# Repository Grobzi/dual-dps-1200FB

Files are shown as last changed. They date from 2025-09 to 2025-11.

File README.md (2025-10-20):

# Dual DPS 1200FB 24V PSU

## Overview
This project demonstrates how to use two HP DPS-1200FB server PSUs in series to create a 24V power supply. An Arduino Nano R4 and a custom PCB are used to monitor and control the PSUs, with a 2.8" Arduino Shield-based touchscreen TFT for user interaction and data display.

## Features
- Monitoring of PSU parameters: current, power draw, temperature and many more.
- Touchscreen user interface (2.8" Arduino-compatible display)
- Control of 12V output in case of failure
- Basic statistics (consumed power per hour)

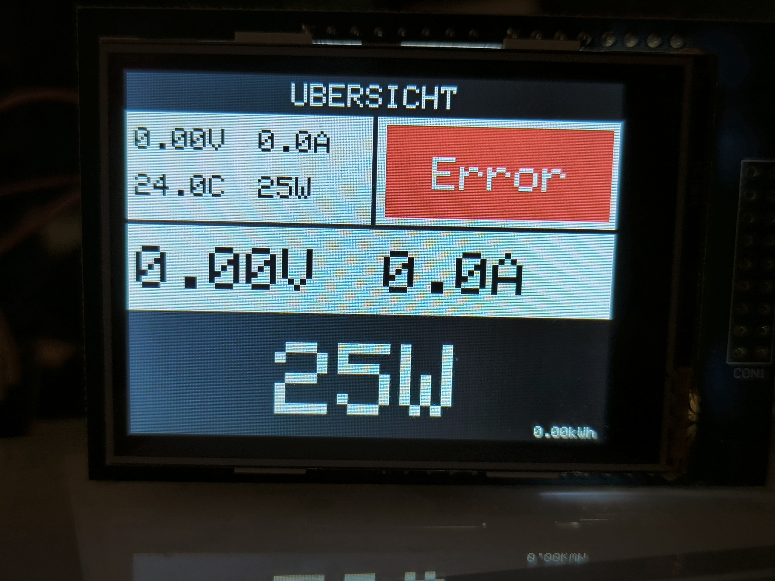
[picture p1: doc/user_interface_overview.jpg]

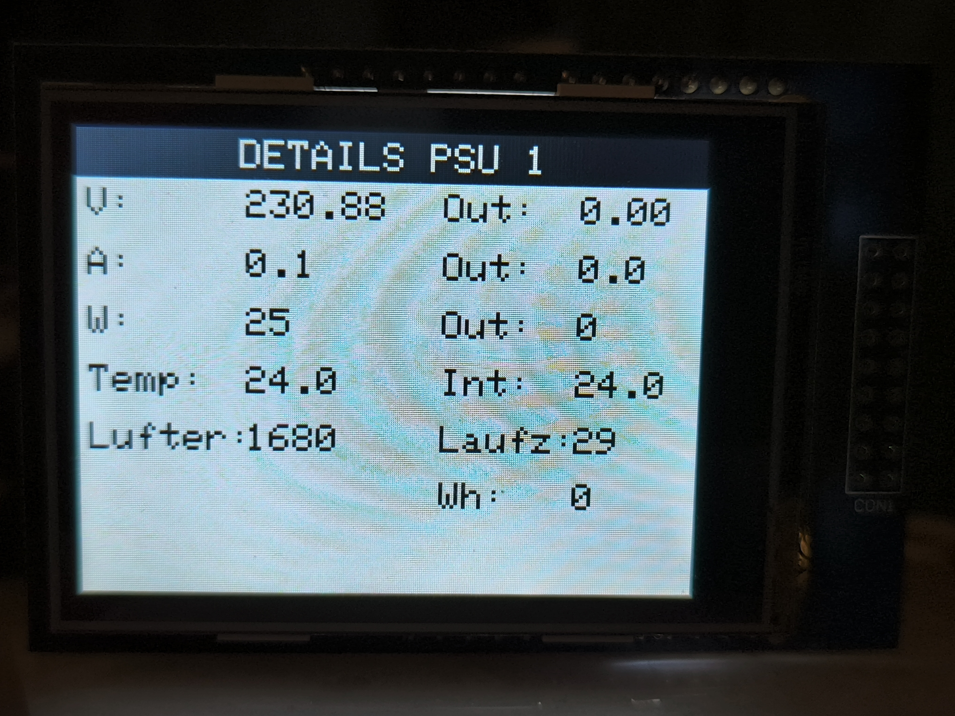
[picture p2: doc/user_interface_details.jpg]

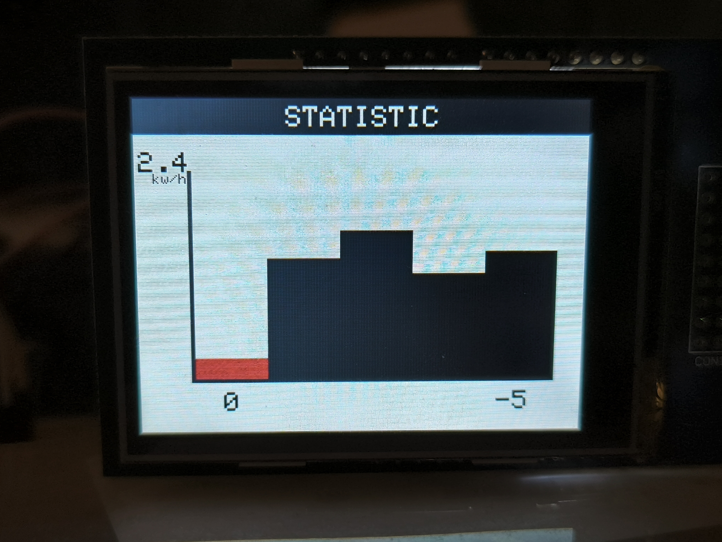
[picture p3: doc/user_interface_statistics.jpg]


## Folder Structure
- `circuit/` - KiCad project files for the custom PCB (WIP)
- `doc/` - Documentation, datasheets, and images
- `src/` - Arduino firmware source code

## Firmware
1. Open `src/PsuPowerMonitor/PsuPowerMonitor.ino` in the Arduino IDE.
2. Install required libraries
    - [MCUFRIEND_kbv](https://github.com/prenticedavid/MCUFRIEND_kbv)
    - [Adafruit GFX Library](https://github.com/adafruit/Adafruit-GFX-Library)
3. Select the correct board and port.
4. Upload the firmware to your microcontroller.

## Contributing
Contributions are welcome! Please open issues or submit pull requests for improvements, bug fixes, or new features.

# Special thanks to
- [DrTune/Raplin](https://github.com/raplin/DPS-1200FB)
- [slundell](https://github.com/slundell/dps_charger)
- [colindt](https://colintd.blogspot.com/2016/10/hacking-hp-common-slot-power-supplies.html)
- [neilp](https://www.rcgroups.com/forums/showpost.php?p=48212083&postcount=29)
- [Philipp Seidel](https://blog.seidel-philipp.de/hp-dps-1200fb-power-supply-hack-for-charging-lipos/)

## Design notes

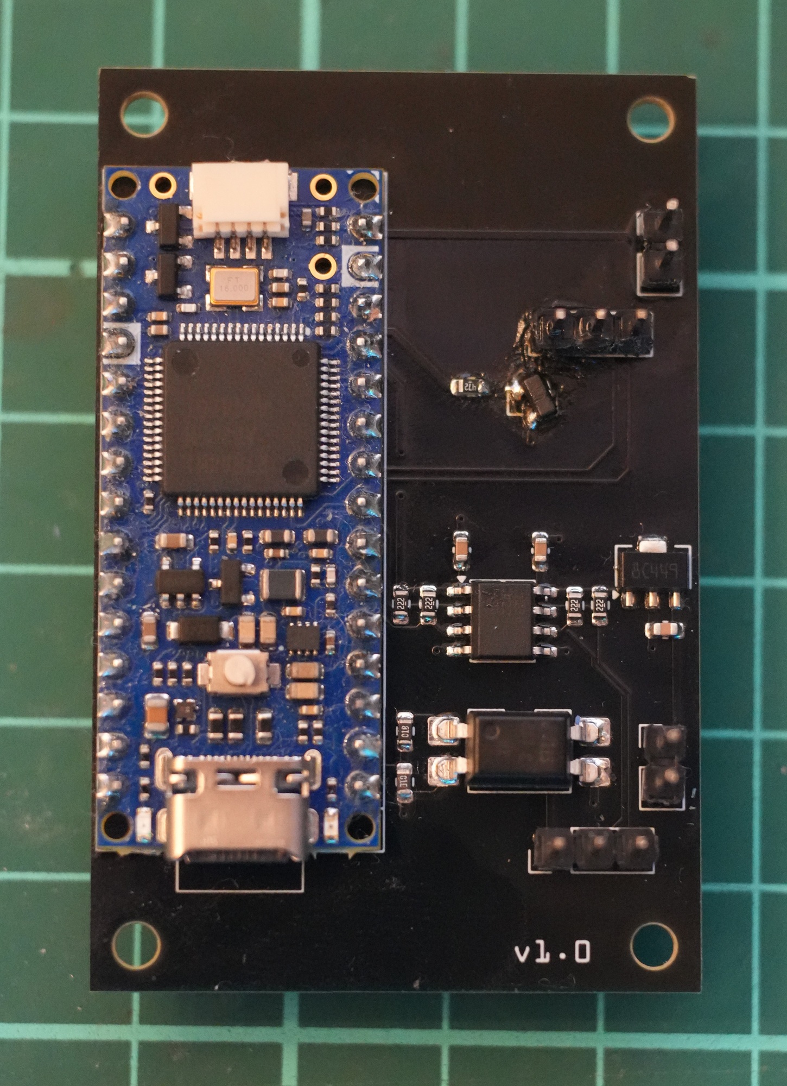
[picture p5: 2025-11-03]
circuit/PCB.JPG

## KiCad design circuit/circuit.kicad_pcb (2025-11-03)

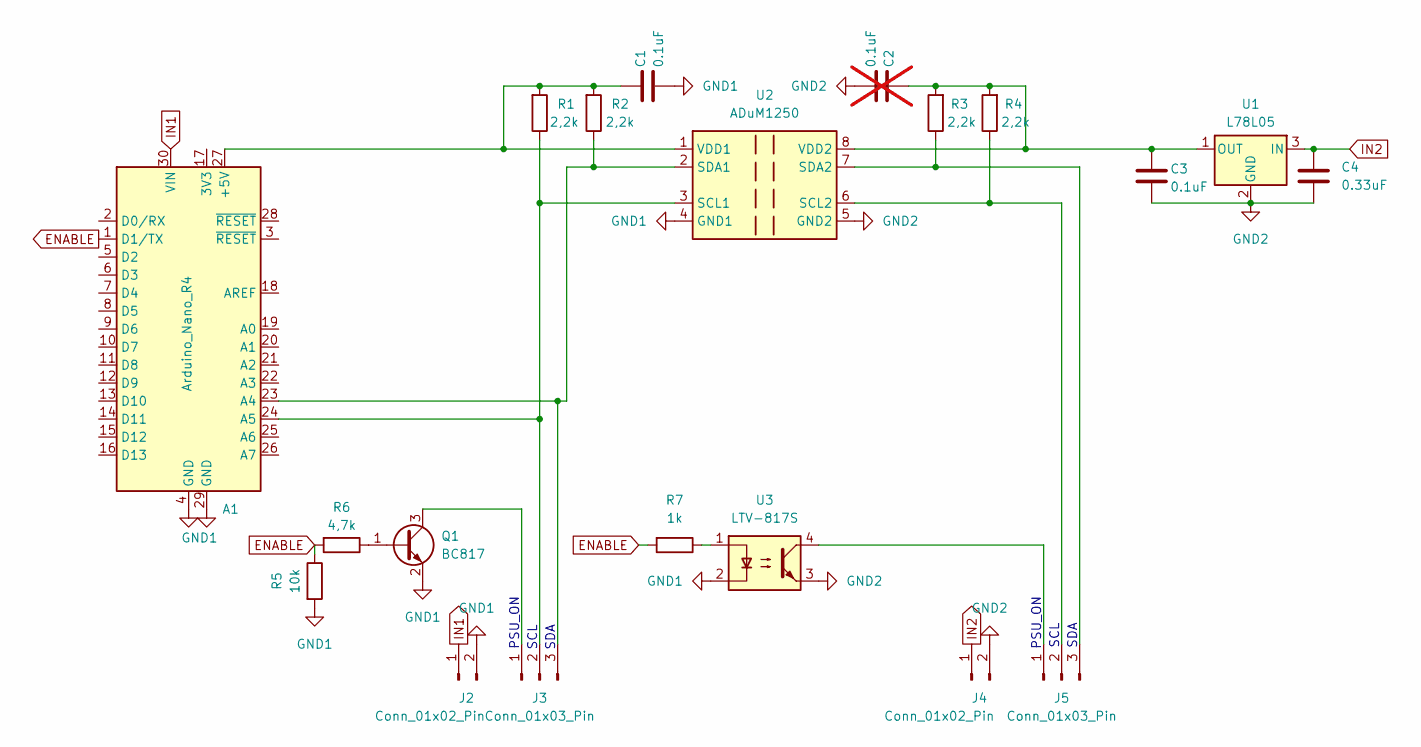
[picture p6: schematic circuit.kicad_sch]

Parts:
A1: Arduino_Nano_R4; Arduino_Nano
C1, C3: 0.1uF; C_0603_1608Metric; LCSC C125205
C2: 0.1uF; C_0603_1608Metric; not fitted
C4: 0.33uF; C_0603_1608Metric; LCSC C107070
J2, J4: Conn_01x02_Pin; PinHeader_1x02_P2.54mm_Vertical; LCSC C492401
J3, J5: Conn_01x03_Pin; PinHeader_1x03_P2.54mm_Vertical; LCSC C2937625
Q1: BC817; SOT-23
R1, R2, R3, R4: 2,2k; R_0603_1608Metric; LCSC C114662
R5: 10k; R_0603_1608Metric; LCSC C98220
R6: 4,7k; R_0603_1608Metric; LCSC C99782
R7: 1k; R_0603_1608Metric; LCSC C22548
U1: L78L05; SOT-89-3; LCSC C42738
U2: ADuM1250; SOIC-8_3.9x4.9mm_P1.27mm; LCSC C579378
U3: LTV-817S; SMDIP-4_W9.53mm; LCSC C109226

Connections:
ENABLE: A1.1 (D1/TX), R5.1, R6.2, R7.2
GND1: A1.4 (GND), A1.29 (GND), C1.2, J2.2, Q1.2 (E), R5.2, U2.4 (GND1), U3.2
GND2: C2.2, C3.2, C4.2, J4.2, U1.2 (GND), U2.5 (GND2), U3.3
IN1: A1.30 (VIN), J2.1
IN2: C4.1, J4.1, U1.3 (IN)
unnamed: A1.27 (+5V), C1.1, R1.2, R2.2, U2.1 (VDD1)
unnamed: A1.23 (A4), J3.3, R2.1, U2.2 (SDA1)
unnamed: A1.24 (A5), J3.2, R1.1, U2.3 (SCL1)
unnamed: J3.1, Q1.3 (C)
unnamed: J5.1, U3.4
unnamed: J5.2, R4.1, U2.6 (SCL2)
unnamed: J5.3, R3.1, U2.7 (SDA2)
unnamed: Q1.1 (B), R6.1
unnamed: R7.1, U3.1
unnamed: C2.1, C3.1, R3.2, R4.2, U1.1 (OUT), U2.8 (VDD2)

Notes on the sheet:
SCL
PSU_ON
SDA

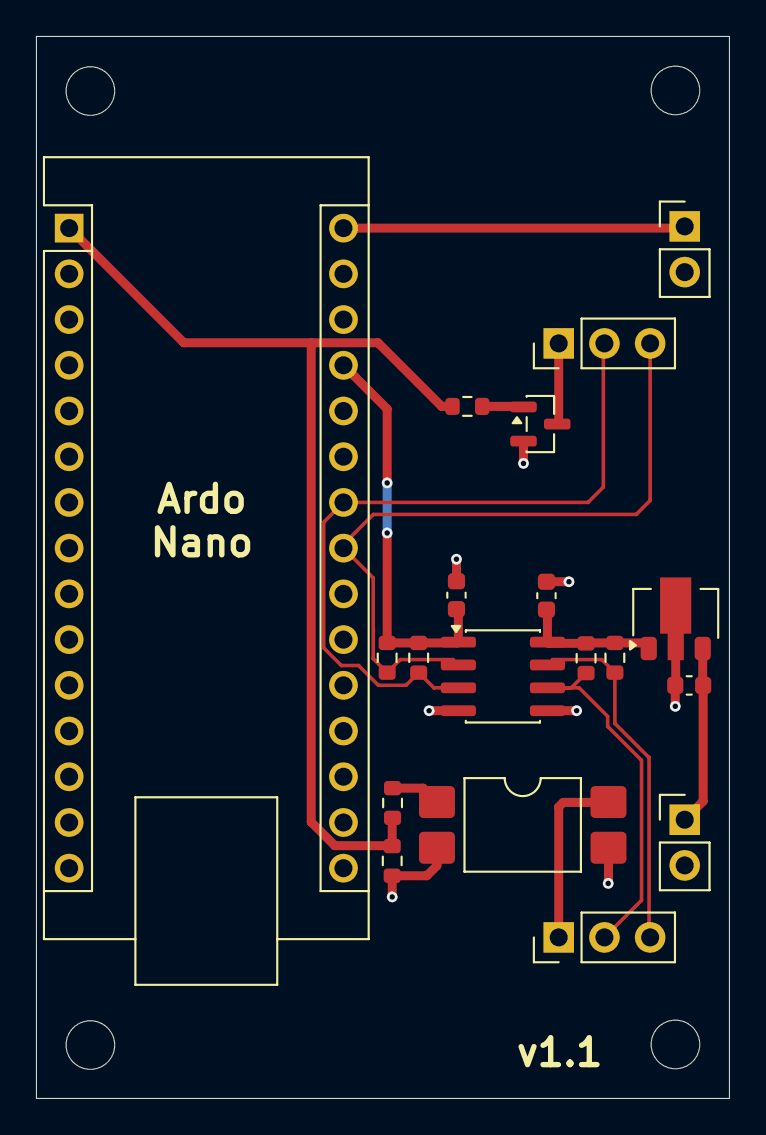
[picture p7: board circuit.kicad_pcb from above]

Board: 2 copper layers, 38.5 x 59.0 mm, 19 parts (0 on the bottom side), 15 nets.

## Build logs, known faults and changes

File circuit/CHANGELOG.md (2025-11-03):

# Changelog

## 1.1
- Use correct pinout for Q1 BC817 transitor.

## 1.0
- Inital PCB and circuit design.

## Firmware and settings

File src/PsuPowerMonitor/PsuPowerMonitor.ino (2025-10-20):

#include "Psu.hpp"
#include "TouchScreen_kbv.h"
#include "Views.hpp"

#include <MCUFRIEND_kbv.h>
#include <Wire.h>
#include <vector>

#define TouchScreen TouchScreen_kbv
#define TSPoint TSPoint_kbv
#define XP 8
#define YP A3
#define XM A2
#define YM 9
#define ENABLE_PIN D1

Psu psu_0 = Psu(0x5F);
Psu psu_1 = Psu(0x5C);
MCUFRIEND_kbv tft;
TouchScreen ts(8, YP, XM, YM, 300);
TSPoint tp;
PsuView view_0 = PsuView(tft, 5, 30);
PsuView view_1 = PsuView(tft, 168, 30);
PsuDetailView detail_view = PsuDetailView(tft, 0, 25);
ChangeableText voltage_text = ChangeableText(tft, 5, 112, 4, BLACK, WHITE);
ChangeableText current_text = ChangeableText(tft, 168, 112, 4, BLACK, WHITE);
ChangeableText power_text = ChangeableText(tft, 180, 175, 7, WHITE, GRAY);
ChangeableText power_combined_text = ChangeableText(tft, 180, 175, 1, WHITE, GRAY);
std::vector<uint32_t> consumption_per_hour = {0};

void setup()
{
    Wire.setTimeout(10);
    Wire.begin();
    Serial.begin(9600);
    pinMode(ENABLE_PIN, PinMode::OUTPUT);
    // while (!Serial);
    tft.begin();
    tft.setRotation(1);
    tft.cp437(true);
}

// State machine variables
enum State
{
    Init,
    Overview,
    Detail,
    Statistics,
    Settings
};
State state = State::Init;
State last_state = State::Init;
int8_t selected_psu;

void display_loop()
{
    static uint32_t last_draw_time = 0;
    uint32_t time = millis();
    if (last_state == state)
    {
        if (time < last_draw_time)
            last_draw_time = 0;
        if (time - last_draw_time < 500)
            return;
    }
    last_draw_time = time;

    if (state == State::Init)
    {
        last_state = state;
        tft.fillScreen(RED);
        tft.setCursor(10, 10);
        tft.setTextColor(WHITE);
        tft.setTextSize(1);
        tft.print("Connect to PSU 1... ");
        delay(100);
        psu_0.connect();
        tft.print(psu_0.connected() ? psu_0.spn.c_str() : "FAILED");
        tft.setCursor(10, 20);
        tft.print("Connect to PSU 2... ");
        delay(100);
        psu_1.connect();
        tft.print(psu_1.connected() ? psu_1.spn.c_str() : "FAILED");
        delay(100);
        if (!psu_0.connected() || !psu_1.connected())
        {
            delay(500);
        }

        state = State::Overview;
    }

    if (state == State::Overview)
    {
        if (last_state != state)
        {
            last_state = state;
            draw_banner(tft, "UBERSICHT");
            tft.fillRect(0, 25, tft.width(), tft.height(), WHITE);
            tft.fillRect(tft.width() / 2 - 1, 25, 3, 70, GRAY);
            tft.fillRect(0, 95, tft.width(), 3, GRAY);
            tft.fillRect(0, 155, tft.width(), 100, GRAY);
            Serial.println("Main layout drawn");
            current_text.set_text("");
            voltage_text.set_text("");
            power_text.set_text("");
            power_combined_text.set_text("");
            view_0.invalidate();
            view_1.invalidate();
        }

        float combined_voltage = 0;
        float combined_current = 0;
        float combined_power = 0;
        float combined_power_used = 0;
        for (int i = 0; i <= 1; i++)
        {
            PsuView *view = &view_0;
            Psu *psu = &psu_0;
            if (i == 1)
            {
                view = &view_1;
                psu = &psu_1;
            }
            if (psu->connected())
            {
                combined_voltage += psu->voltage_out();
                combined_current += psu->current_out();
                combined_power += psu->power_in();
                combined_power_used += psu->power_consumed();
                view->set_state(PsuState::normal);
                view->initial_draw();
                view->update_draw(format_precision(psu->voltage_out(), 2), format_precision(psu->current_out(), 1),
                                  format_precision(psu->temperature_internal(), 1),
                                  format_precision(psu->power_in(), 0));
            }
            else
            {
                view->set_state(PsuState::error);
                view->initial_draw();
            }
        }

        voltage_text.set_text(format_precision(combined_voltage, 2) + "V");
        current_text.set_text(format_precision(combined_current / 2, 1) + "A");
        int16_t x1, y1;
        uint16_t w, h;
        std::string text = format_precision(combined_power, 0) + "W";
        tft.setTextSize(7);
        tft.getTextBounds(text.c_str(), 0, 0, &x1, &y1, &w, &h);
        power_text.set_text(text, (tft.width() - w) / 2, 175);

        text = format_precision(combined_power_used / 1000, 2) + "kWh";
        tft.setTextSize(1);
        tft.getTextBounds(text.c_str(), 0, 0, &x1, &y1, &w, &h);
        power_combined_text.set_text(text, (tft.width() - w - 5), 230);
    }

    if (state == State::Detail)
    {
        if (last_state != state)
        {
            last_state = state;
            detail_view.invalidate();
            if (selected_psu == 0)
                draw_banner(tft, "DETAILS PSU 1");
            if (selected_psu == 1)
                draw_banner(tft, "DETAILS PSU 2");
            detail_view.initial_draw();
        }
        Psu *psu = &psu_0;
        if (selected_psu == 1)
            psu = &psu_1;
        if (psu->connected())
            detail_view.update_draw(
                format_precision(psu->voltage_in(), 2), format_precision(psu->voltage_out(), 2),
                format_precision(psu->current_in(), 1), format_precision(psu->current_out(), 1),
                format_precision(psu->power_in(), 0), format_precision(psu->power_out(), 0),
                format_precision(psu->temperature_intake(), 1), format_precision(psu->temperature_internal(), 1),
                format_precision(psu->fan_speed(), 0), format_precision(psu->seconds_since_startup(), 0),
                format_precision(psu->power_consumed(), 0));
    }

    if (state == State::Statistics)
    {
        constexpr int graph_width = 260;
        constexpr int graph_height = 150;
        constexpr int bars_count = 5;
        constexpr int bars_width = graph_width / bars_count;
        constexpr int x_pos = 40;

        static auto last_hour = 0;
        if (last_state != state || last_hour != consumption_per_hour.size())
        {
            last_hour = consumption_per_hour.size();
            last_state = state;
            draw_banner(tft, "STATISTIC");
            tft.fillRect(0, 25, tft.width(), tft.height(), WHITE);
            tft.fillRect(x_pos - 3, 200, graph_width + 3, 3, GRAY);
            tft.fillRect(x_pos - 3, 200, 3, -graph_height, GRAY);
            tft.setTextColor(BLACK);
            tft.setCursor(x_pos + 20, 210);
            tft.print("0");
            tft.setCursor(258, 210);
            tft.print("-5");
            tft.setCursor(3, 37);
            tft.print("2.4");
            tft.setTextSize(1);
            tft.setCursor(13, 52);
            tft.print("kw/h");
            for (int i = 0; i < bars_count; i++)
            {
                if (i >= consumption_per_hour.size())
                    break;
                // Maximum should be 2400Wh
                auto consumption = consumption_per_hour[consumption_per_hour.size() - i - 1];
                auto bar_height = (consumption / 2400.f) * graph_height;
                tft.fillRect(x_pos + bars_width * i, 200, bars_width, -bar_height, GRAY);
            }
        }

        static uint32_t flicker = 0;
        flicker++;
        auto consumption = consumption_per_hour.back();
        auto bar_height = (consumption / 2400.f) * graph_height;
        bar_height = std::max(1.f, bar_height);
        if (flicker % 2)
            tft.fillRect(x_pos, 200, bars_width, -bar_height, GRAY);
        else
            tft.fillRect(x_pos, 200, bars_width, -bar_height, RED);
    }
}

void collect_statistics_loop()
{
    static uint32_t last_time = 0;
    uint32_t time = millis();
    if (time < last_time)
        last_time = 0;
    if (time - last_time < 1000 * 30)
        return;
    last_time = time;

    auto hour = millis() / 1000 / 60 / 60;
    if (hour >= consumption_per_hour.size())
        consumption_per_hour.push_back(0);
    auto consumed = psu_0.power_consumed() + psu_1.power_consumed();
    for (int i = 0; i < hour; i++)
        consumed -= consumption_per_hour[i];
    Serial.print("Refresh statistics for hour ");
    Serial.println(hour);
    consumption_per_hour[hour] = consumed;
}

void touch_loop()
{
    auto p = ts.getPoint();
    // restore shared pins
    pinMode(YP, OUTPUT);
    pinMode(XM, OUTPUT);
    digitalWrite(YP, HIGH);
    digitalWrite(XM, HIGH);
    if (p.z < 100)
        return;
    auto x = map(p.y, 913, 165, 0, tft.width());
    auto y = map(p.x, 172, 846, 0, tft.height());
    Serial.print("Touch on: ");
    Serial.print(x);
    Serial.print("x");
    Serial.print(y);
    Serial.print("|");
    Serial.println(p.z);
    if (state == State::Init)
    {
        // No touch operation
    }

    if (state == State::Overview)
    {
        if (x > 0 && x < 150 && y > 30 && y < 80)
        {
            selected_psu = 0;
            state = State::Detail;
            display_loop();
        }
        else if (x > 210 && x < 300 && y > 30 && y < 80)
        {
            selected_psu = 1;
            state = State::Detail;
            display_loop();
        }
        else if (y > 180)
        {
            state = State::Statistics;
            display_loop();
        }
    }

    if (state == State::Detail)
    {
        if (y > 0 && y < 40)
        {
            selected_psu = -1;
            state = State::Overview;
            display_loop();
        }
    }
    if (state == State::Statistics)
    {
        if (y > 0 && y < 40)
        {
            state = State::Overview;
            display_loop();
        }
    }
}

uint32_t output_error_time = 0;
bool output_error = false;

void enable_signal_loop()
{
    if (psu_0.connected() && psu_0.voltage_in() > 0 && psu_1.connected() && psu_1.voltage_in() > 0)
    {
        if (!output_error)
            digitalWrite(ENABLE_PIN, PinStatus::HIGH);

        // Make sure that  300ms after the outputs are enabled the PSUs outputs are active
        // If not switch the outputs off again.
        if (psu_0.voltage_out() <= 0 || psu_1.voltage_out() <= 0)
        {
            if (output_error_time == 0)
            {
                output_error_time = millis();
            }
            if (millis() - output_error_time > 300)
            {
                digitalWrite(ENABLE_PIN, PinStatus::LOW);
                output_error = true;
            }
        }
        else
        {
            output_error_time = 0;
        }
    }
    else
    {
        digitalWrite(ENABLE_PIN, PinStatus::LOW);
    }
}

void loop()
{
    uint32_t start = millis();
    enable_signal_loop();
    display_loop();
    touch_loop();
    collect_statistics_loop();

    uint32_t end = millis();
    // Serial.print("Main loop ms:");
    // Serial.println(std::to_string(end - start).c_str());
    delay(5);
}

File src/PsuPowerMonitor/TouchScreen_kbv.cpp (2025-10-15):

// Touch screen library with X Y and Z (pressure) readings as well
// as oversampling to avoid 'bouncing'
// adapted from (c) ladyada / adafruit

#include "Arduino.h"

#include "TouchScreen_kbv.h"

#define NUMSAMPLES 3                       //.kbv
#if defined(__STM32F1__) || defined(ESP32) // Maple core
#define ADC_ADJUST >> 2
#else
#define ADC_ADJUST
#endif

TSPoint_kbv::TSPoint_kbv(void)
{
    x = y = 0;
}

TSPoint_kbv::TSPoint_kbv(int16_t x0, int16_t y0, int16_t z0)
{
    x = x0;
    y = y0;
    z = z0;
}

bool TSPoint_kbv::operator==(TSPoint_kbv p1)
{
    return ((p1.x == x) && (p1.y == y) && (p1.z == z));
}

bool TSPoint_kbv::operator!=(TSPoint_kbv p1)
{
    return ((p1.x != x) || (p1.y != y) || (p1.z != z));
}

static void insert_sort(int array[], uint8_t size)
{
    uint8_t j;
    int save;

    for (int i = 1; i < size; i++)
    {
        save = array[i];
        for (j = i; j >= 1 && save < array[j - 1]; j--)
            array[j] = array[j - 1];
        array[j] = save;
    }
}

TSPoint_kbv TouchScreen_kbv::getPoint(void)
{
    int x, y, z;
    int samples[NUMSAMPLES];
    uint8_t i, valid;

    valid = 1;

    pinMode(_yp, INPUT);
    pinMode(_ym, INPUT);

    digitalWrite(_yp, LOW);
    digitalWrite(_ym, LOW);

    pinMode(_xp, OUTPUT);
    pinMode(_xm, OUTPUT);
    digitalWrite(_xp, HIGH);
    digitalWrite(_xm, LOW);

    for (i = 0; i < NUMSAMPLES; i++)
    {
        samples[i] = analogRead(_yp) ADC_ADJUST;
    }
    insert_sort(samples, NUMSAMPLES);
    x = (1023 - samples[NUMSAMPLES / 2]); // choose median

    pinMode(_xp, INPUT);
    pinMode(_xm, INPUT);
    digitalWrite(_xp, LOW);
    digitalWrite(_xm, LOW); //.kbv for Due

    pinMode(_yp, OUTPUT);
    digitalWrite(_yp, HIGH);
    pinMode(_ym, OUTPUT);
    digitalWrite(_ym, LOW); //.kbv for Due

    for (i = 0; i < NUMSAMPLES; i++)
    {
        samples[i] = analogRead(_xm) ADC_ADJUST;
    }

    insert_sort(samples, NUMSAMPLES);

    y = (1023 - samples[NUMSAMPLES / 2]);

    // Set X+ to ground
    pinMode(_xp, OUTPUT);
    digitalWrite(_xp, LOW);

    // Set Y- to VCC
    pinMode(_ym, OUTPUT); //.kbv
    digitalWrite(_ym, HIGH);

    // Hi-Z X- and Y+
    digitalWrite(_xm, LOW); //.kbv
    pinMode(_xm, INPUT);    //.kbv
    digitalWrite(_yp, LOW);
    pinMode(_yp, INPUT);

    int z1 = analogRead(_xm) ADC_ADJUST;
    int z2 = analogRead(_yp) ADC_ADJUST;

    z = (1023 - (z2 - z1));

    return TSPoint_kbv(x, y, z); // XM, YP still in ANALOG mode
}

TouchScreen_kbv::TouchScreen_kbv(uint8_t xp, uint8_t yp, uint8_t xm, uint8_t ym)
{
    _yp = yp;
    _xm = xm;
    _ym = ym;
    _xp = xp;
    _rxplate = 0;
    pressureThreshhold = 10;
}

TouchScreen_kbv::TouchScreen_kbv(uint8_t xp, uint8_t yp, uint8_t xm, uint8_t ym, uint16_t rxplate)
{
    _yp = yp;
    _xm = xm;
    _ym = ym;
    _xp = xp;
    _rxplate = rxplate;

    pressureThreshhold = 10;
}

int TouchScreen_kbv::readTouchX(void)
{
    pinMode(_yp, INPUT);
    pinMode(_ym, INPUT);
    digitalWrite(_yp, LOW);
    digitalWrite(_ym, LOW);

    pinMode(_xp, OUTPUT);
    digitalWrite(_xp, HIGH);
    pinMode(_xm, OUTPUT);
    digitalWrite(_xm, LOW);

    return (1023 - (analogRead(_yp))ADC_ADJUST);
}

int TouchScreen_kbv::readTouchY(void)
{
    pinMode(_xp, INPUT);
    pinMode(_xm, INPUT);
    digitalWrite(_xp, LOW);
    digitalWrite(_xm, LOW);

    pinMode(_yp, OUTPUT);
    digitalWrite(_yp, HIGH);
    pinMode(_ym, OUTPUT);
    digitalWrite(_ym, LOW);

    return (1023 - (analogRead(_xm))ADC_ADJUST);
}

uint16_t TouchScreen_kbv::pressure(void)
{
    // Set X+ to ground
    pinMode(_xp, OUTPUT);
    digitalWrite(_xp, LOW);

    // Set Y- to VCC
    pinMode(_ym, OUTPUT);
    digitalWrite(_ym, HIGH);

    // Hi-Z X- and Y+
    digitalWrite(_xm, LOW);
    pinMode(_xm, INPUT);
    digitalWrite(_yp, LOW);
    pinMode(_yp, INPUT);

    int z1 = analogRead(_xm) ADC_ADJUST;
    int z2 = analogRead(_yp) ADC_ADJUST;

    return (1023 - (z2 - z1));
}

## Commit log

2025-09-25 added initial files
    [circuit.kicad_pcb, circuit.kicad_sch]
2025-10-15 Added formatting. Added enable pin logic.
2025-11-03 Updated PCB layout and circuit.
    [circuit.kicad_pcb, circuit.kicad_sch]
